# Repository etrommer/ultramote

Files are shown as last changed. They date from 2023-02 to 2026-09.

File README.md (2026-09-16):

# Overview
For a general overview as well as automatically updated documentation, please refer to the [Ultramote website](https://etrommer.github.io/ultramote/)

## Firmware debugging

The firmware debug configuration uses a Black Magic Probe directly as a GDB remote target. It does not require an OpenOCD or pyOCD server. Install `arm-none-eabi-gdb`, build the firmware, and start a direct session with:

```bash
cd firmware
make
arm-none-eabi-gdb build/firmware.elf -x blackmagic.gdb
```

The two Cortex-Debug profiles provide either a flash-and-launch session or an attach-only session.

## Firmware development container

The repository includes a VS Code Dev Container with the pinned STM32CubeMX 6.16.0
Linux package, the STM32CubeWL 1.3.0 firmware package, the GNU Arm Embedded toolchain,
GDB, OpenOCD, and ST-Link tools. Open the repository in VS Code and run **Dev
Containers: Reopen in Container**. The container opens `firmware` as the VS Code
workspace; the repository root is available at `..`.

Build the firmware inside the container:

```bash
make
```

Regenerate CubeMX-managed files from the IOC file without opening a GUI:

```bash
cubemx-generate firmware.ioc
make
```

The image verifies both downloaded archives with SHA-256 checksums. The ST-Link or
Black Magic Probe device must be passed through to the container separately when
debugging; the image does not assume a host device path.

The `pyocd` server type is an alternative only when the connected probe exposes a CMSIS-DAP interface. It is not the transport used by a Black Magic Probe's native GDB interface.

# Firmware
## Remove Lora-E5 readout protection
The Seeedstudio Lora-E5 comes with a preloaded firmware and readout protection enabled. This needs to be disabled before other firmware can be flashed. Run:
```bash
openocd -f interface/stlink.cfg -f target/stm32wlx.cfg
```
then connect to the OpenOCD session from another terminal, using: `nc localhost 4444`. In the telnet session, run:
```
init
reset halt
stm32wlx unlock 0
reset halt
exit
```

# Hardware
## Documentation
Schematics, BoM, Gerber files etc. are generated with the [KiCad command line
interface](https://docs.kicad.org/master/en/cli/cli.html). Change to the `pcb`
directory and run:

```bash
cd pcb
make
```

This generates all documentation in the local subfolder `generated`. `make
docs`, `make fab`, `make step`, `make render` and `make ibom` build single
groups, and `make OUT=<dir>` writes the assets somewhere else. `make` needs
KiCad 10 (`kicad-cli`) and `bsdtar`.

CI runs the same build and publishes the result together with the website
(`.github/workflows/website.yml`). The assets are build output: they are not
committed to the repository, so a local site preview needs

```bash
make -C pcb OUT=website/static/pcb_assets
```

Building the website itself needs Zola 0.22 (`zola --root website build`); 0.23
and later cannot build it, as they replaced the template engine with one that no
longer supports the macros used by the site templates and the `juice` theme.

The interactive BoM needs the
[InteractiveHtmlBom](https://github.com/openscopeproject/InteractiveHtmlBom)
CLI, which must see KiCad's Python bindings. `make` uses one from `PATH` if there
is one, otherwise the copy that ships with the plugin installed through KiCad's
Plugin and Content Manager, so a plugin installation needs no extra setup. Point
`IBOM=` at a CLI from elsewhere (CI installs one from PyPI):

```bash
python3 -m venv --system-site-packages ~/.local/venv/ibom
~/.local/venv/ibom/bin/pip install interactivehtmlbom
make IBOM=~/.local/venv/ibom/bin/generate_interactive_bom
```

If you think that an important piece of documentation is missing, please open an issue.

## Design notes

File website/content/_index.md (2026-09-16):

+++
title = "List of blog posts"
sort_by = "weight"
+++
Ultramote is a long-distance remote trigger system. It is built for photography first, but easily supports all kinds of equipment. Ultramote uses LoRa long-distance radio communication to achieve distances of hunreds of meters, even in urban environments - well above the range of commercially-available 2.4GHz triggering systems. Ultramote lets you put a camera in places where you _really_ don't want to be and allows you to capture shots from a safe distance.

# Hardware
## Interface
Ultramote has two 2.5mm jacks for input and output. Each input/output has two independent channels (tip and sleeve). Output connectors are optically isolated from the Ultramote's electronics, inputs are equipped with high-voltage protection circuitry. Any regular remote shutter or time lapse controller can be connected and is relayed to all Ultramotes listening on the same channel. For camera output, an adapter cable from a 2.5mm jack to the camera's remote port is required.

Ultramote can be connected to a PC via USB-C and controlled via a Serial Terminal.

Firmware updates can also be carried out over USB-C.

## Battery
A 400mAh LiPo battery allows for an idle time of several hours. The battery is charged over USB-C.

## Enclosure
_work in progress_  
The Ultramote's enclosure is 3D-printed in two parts and comes with hotshoe and GoPro-style attachement points as well as a 1/4" thread.

## Extendable
Ultramote is ready to connect to Sparkfun's [QWIIC](https://www.sparkfun.com/qwiic) sensors. This makes it a versatile platform that can support all sorts of sophisticated applications. Want to trigger a remote device depending on temperature, incident light, air pressure, sound, an ultrasonic distance measurement, etc? Integrate your QWIIC sensor into the firmware, flash it using USB and you are good to go!

## Documentation
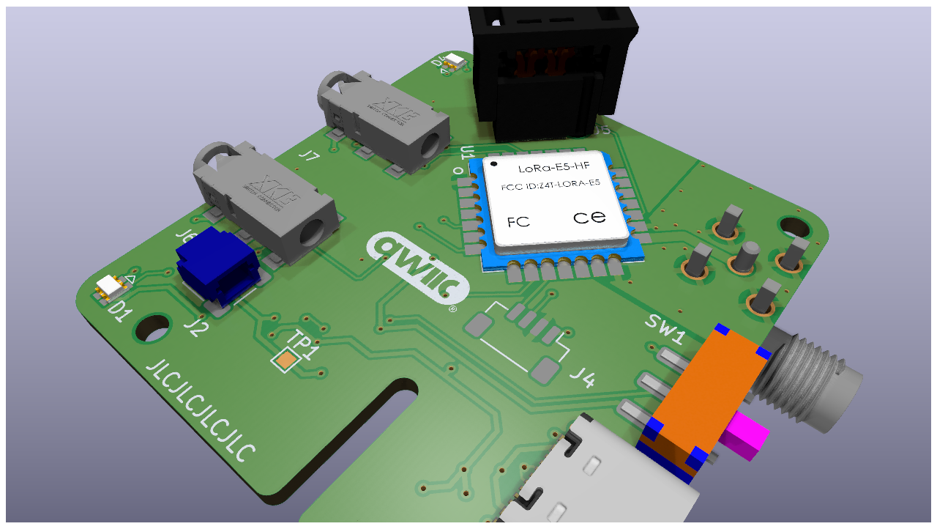
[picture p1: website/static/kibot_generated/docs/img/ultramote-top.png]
Rendering Top

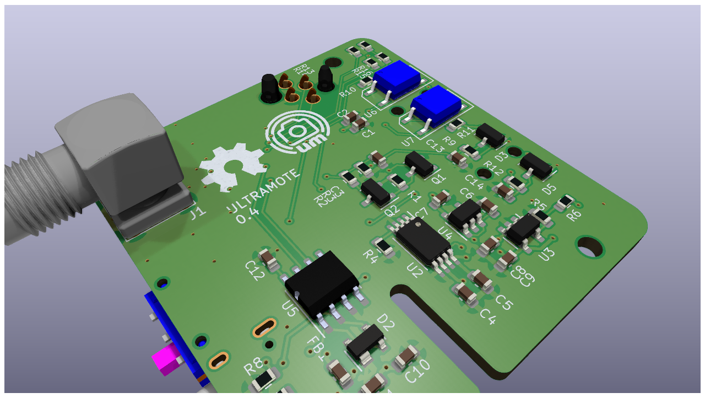
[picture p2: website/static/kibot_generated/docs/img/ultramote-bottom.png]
Rendering Bottom


Documentation is built from the KiCad sources by the `pcb/Makefile` and automatically updated from the repository's main branch
- [Schematic (PDF)](pcb_assets/docs/ultramote-schematic.pdf)
- [Board Layout (PDF)](pcb_assets/docs/ultramote-pcb-layers.pdf)
- [BoM (CSV)](pcb_assets/docs/bom/bom_ultramote.csv)
- [Interactive BoM](pcb_assets/docs/bom/ultramote-ibom.html) (generated using the [KiCAD IBoM Plugin](https://github.com/openscopeproject/InteractiveHtmlBom))
- [CAD File (STEP)](pcb_assets/ultramote.step)

# Firmware
The firmware currently supports these features:
- Pass on trigger events to other devices listening on the same channel
- Report battery voltage
- Command-line interface over USB/Serial. Over the interface, users can:
    - Put the device in bootloader mode to flash firmware over USB. This allows users to easily update their device or develop their own firmware.
    - Reprogram the device to a different channel. Useful when triggering more than one camera.
    - Select LED modes, set the state of the output, inspect device state, etc.

There is a long list of potential features that _might_ be added at a later point in time.

# License
Ultramote Hardware and Software are licensed under the [GNU General Public License v3.0](https://github.com/etrommer/ultramote/tree/main/LICENSE)

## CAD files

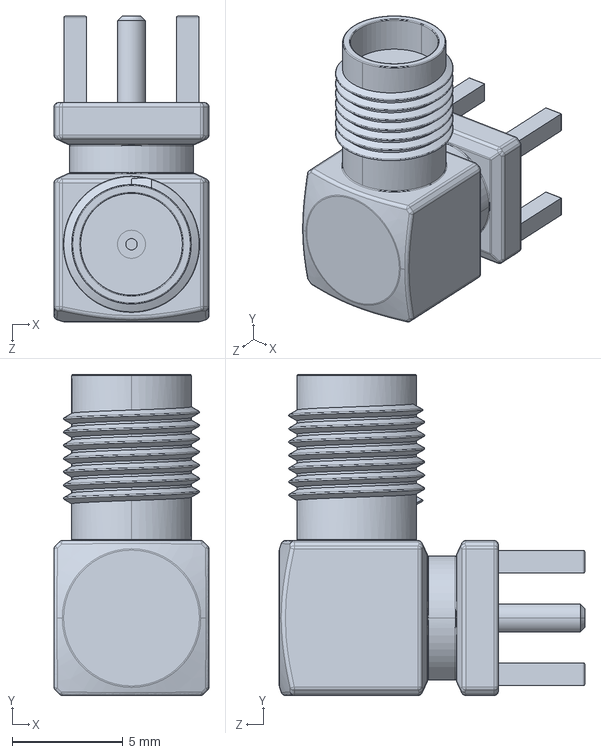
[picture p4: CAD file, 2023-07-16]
pcb/cad_models/SMA ANGLED.STEP
7.00 x 14.5 x 13.8 mm

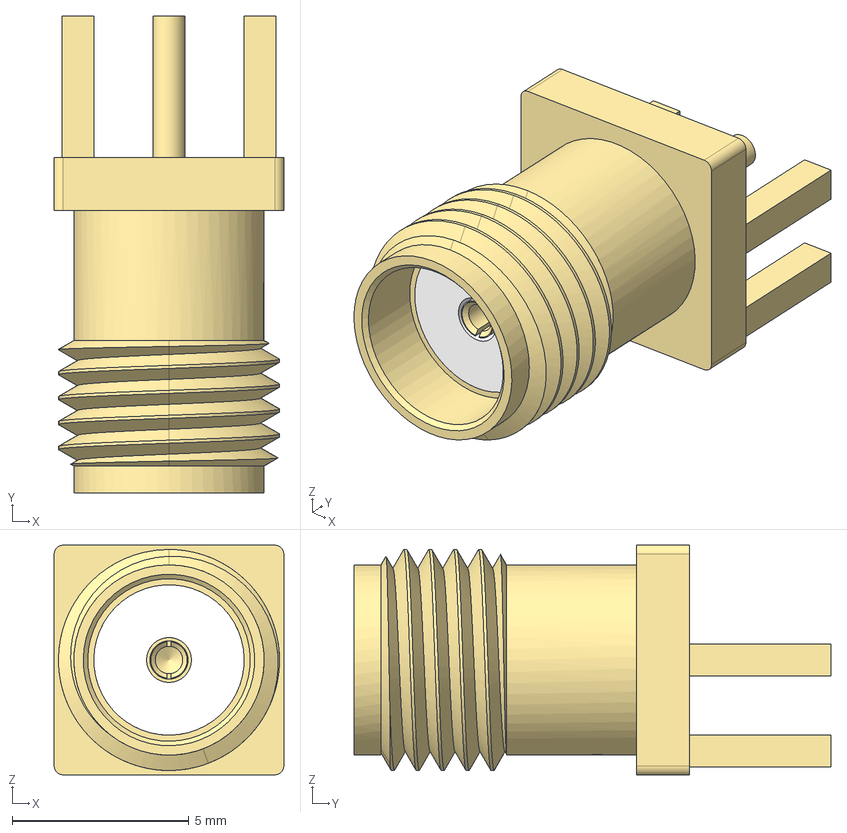
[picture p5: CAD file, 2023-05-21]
pcb/cad_models/SMA_female_edge_6.5x6.5.step
6.50 x 13.5 x 6.50 mm
Dielectric
Pin

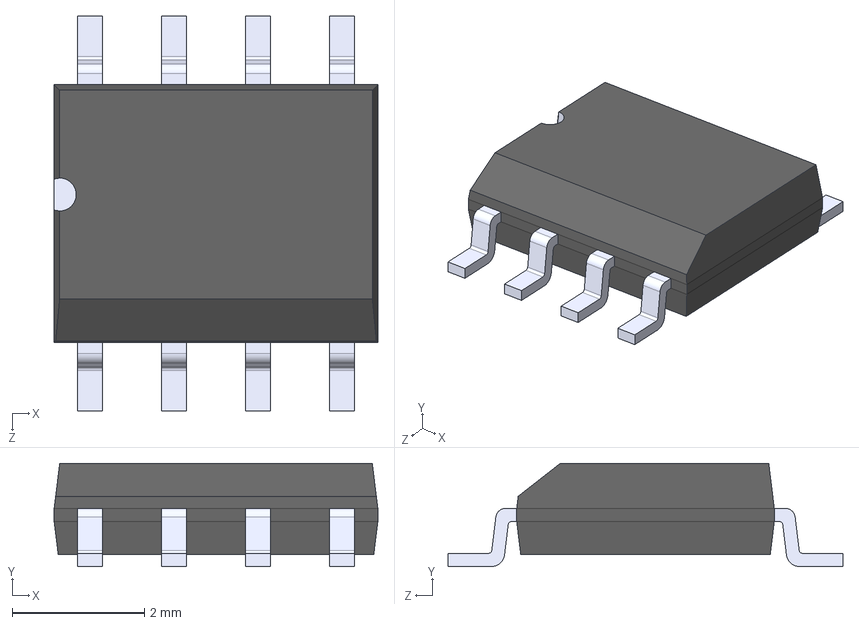
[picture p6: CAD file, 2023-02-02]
pcb/cad_models/sop8.STEP
4.90 x 1.56 x 5.98 mm
User Library-sop8_model_pin5to8_sop8 x 8
User Library-sop8_model_sop8_body

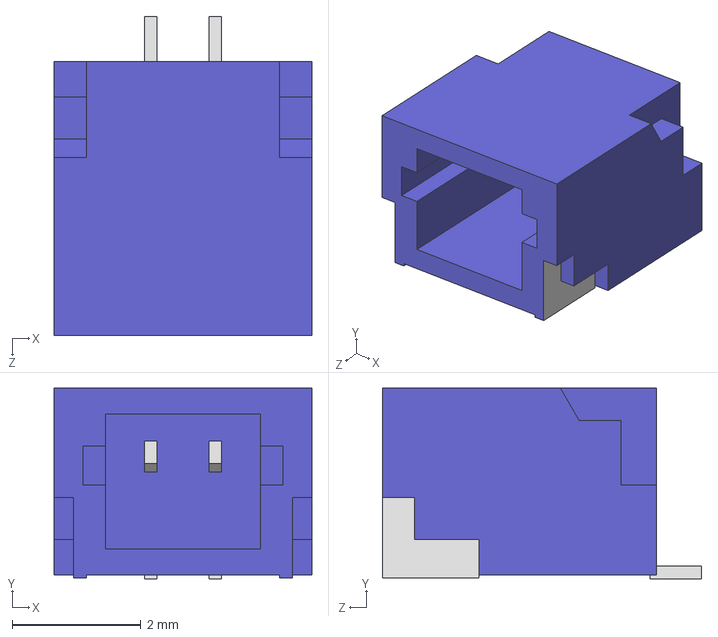
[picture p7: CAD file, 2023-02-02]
pcb/cad_models/SM02B-SRSS-TB.STEP
4.00 x 2.96 x 4.95 mm

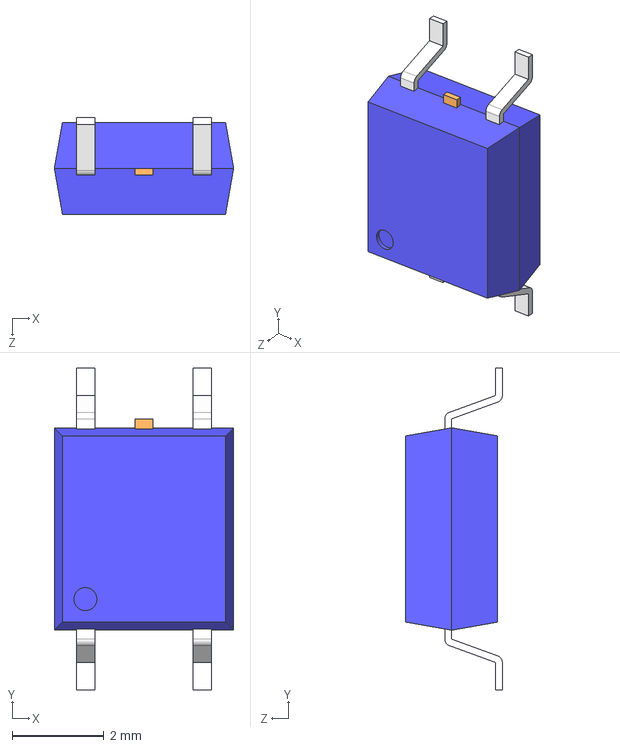
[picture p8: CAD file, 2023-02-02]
pcb/cad_models/sop4.STEP
3.90 x 7.00 x 2.10 mm

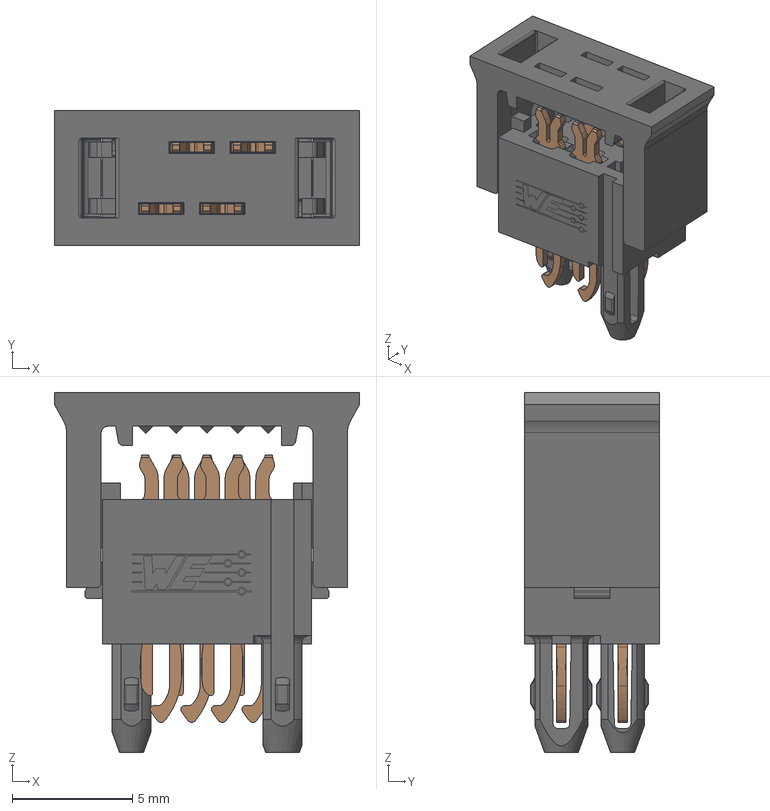
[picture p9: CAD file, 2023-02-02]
pcb/cad_models/redfit_idc_6.stp
12.7 x 5.60 x 15.0 mm
CT422_00.4.1.1_0 x 4
BS698_4_00.4_0000_0
BS697_4_00.6_0000_0

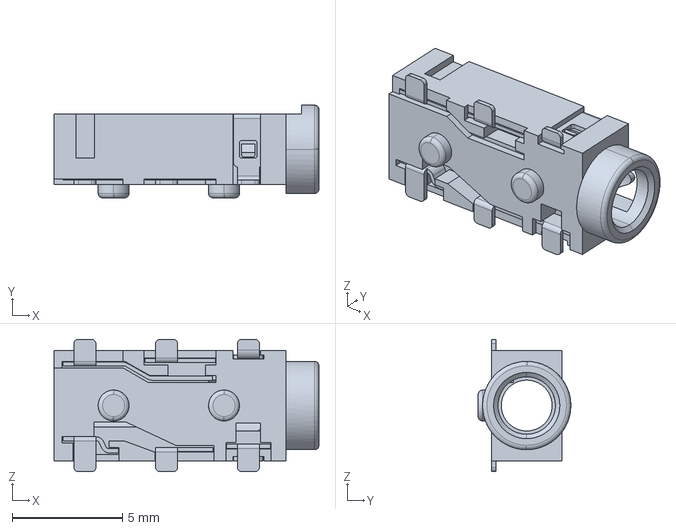
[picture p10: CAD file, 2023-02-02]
pcb/cad_models/pj-242d-smt.stp
12.0 x 4.20 x 6.00 mm

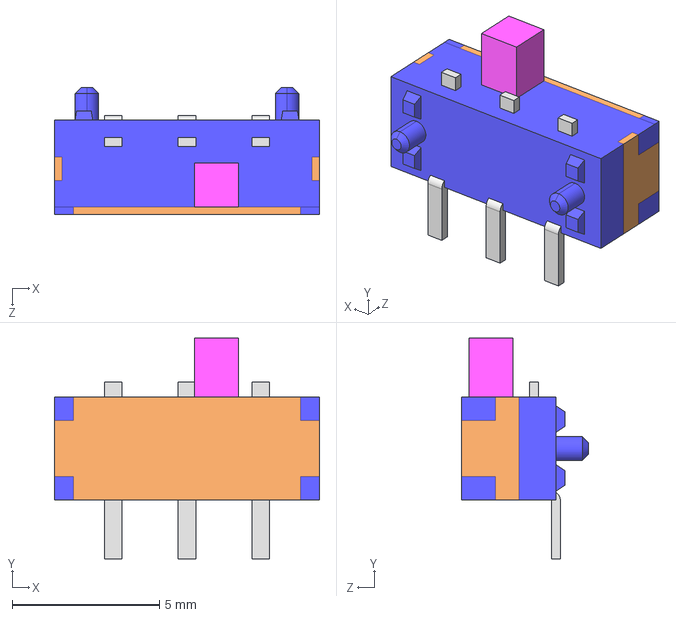
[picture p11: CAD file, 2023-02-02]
pcb/cad_models/SSSS211603.STEP
9.00 x 7.50 x 4.30 mm

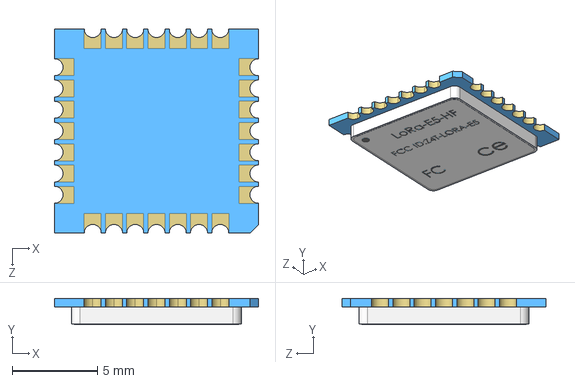
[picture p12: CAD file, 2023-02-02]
pcb/cad_models/lorae5.STEP
12.0 x 1.53 x 12.0 mm

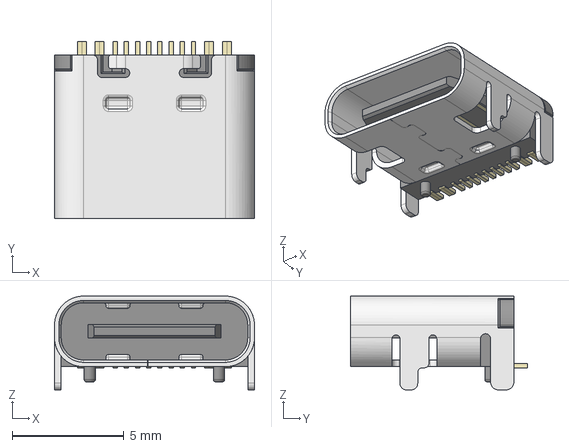
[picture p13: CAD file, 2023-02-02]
pcb/cad_models/USB-C.step
8.95 x 7.90 x 4.20 mm

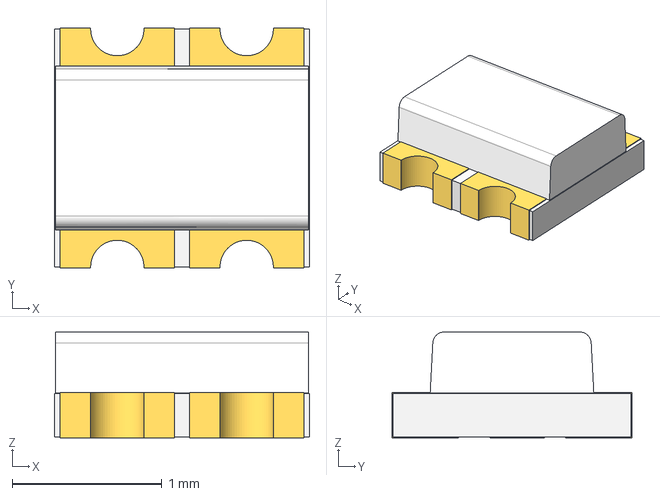
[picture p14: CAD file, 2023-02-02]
pcb/cad_models/led_0606.stp
1.70 x 1.60 x 0.707 mm

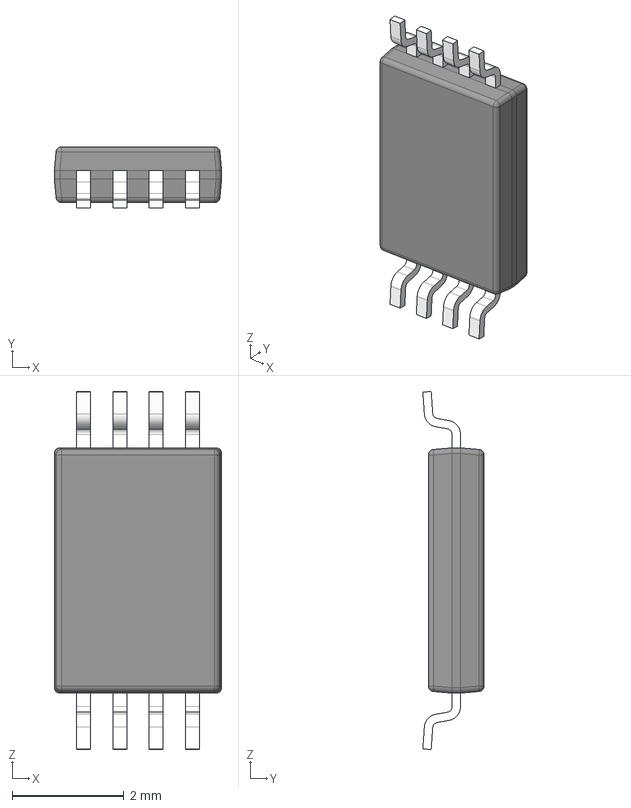
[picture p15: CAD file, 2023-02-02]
pcb/cad_models/tssop8.stp
3.00 x 1.10 x 6.42 mm
BODY-SO
LEAD-SO x 8
PIN1-ID

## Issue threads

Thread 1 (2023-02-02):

Redfit Connector registration pin does not fit

etrommer, 2023-02-02:
One of the registration pins of the Debug connector is larger than the other, but both NPTHs are the same size, so one is a very tight fit.

Fix footprint according to datasheet: https://www.we-online.com/components/products/datasheet/490107670412.pdf

Closed 2023-02-02.

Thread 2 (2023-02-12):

Charge LED is faintly lit when USB is not connected

etrommer, 2023-02-12:
The Lipo charge LED is faintly lit when VBUS = 0V, likely due to backpowering from the MCP73831.

Solution: Power LED from VBUS instead of 3V3. Check if 220 Ohm is still sufficient, as VBUS is 5V.

Closed 2023-06-19.

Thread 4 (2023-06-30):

Assign OUTPUT_TIP to another Pin

etrommer, 2023-06-30:
`OUTPUT_TIP` is currently assigned to `PB0` which interferes with the STM32 clocks.

Pin should be left floating and `OUTPUT_TIP` assigned to another GPIO.

Closed 2023-07-16.

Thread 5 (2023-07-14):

Add I2C/QWIIC capability

etrommer, 2023-07-14:
Adding the capability to easily add I2C sensors etc. might be a good idea to increase versatility and reuse.
`PB6` and `PB9` of `I2C1` are not currently used and could support a [QWIIC connector](https://www.sparkfun.com/qwiic) footprint.

Closed 2023-07-16.

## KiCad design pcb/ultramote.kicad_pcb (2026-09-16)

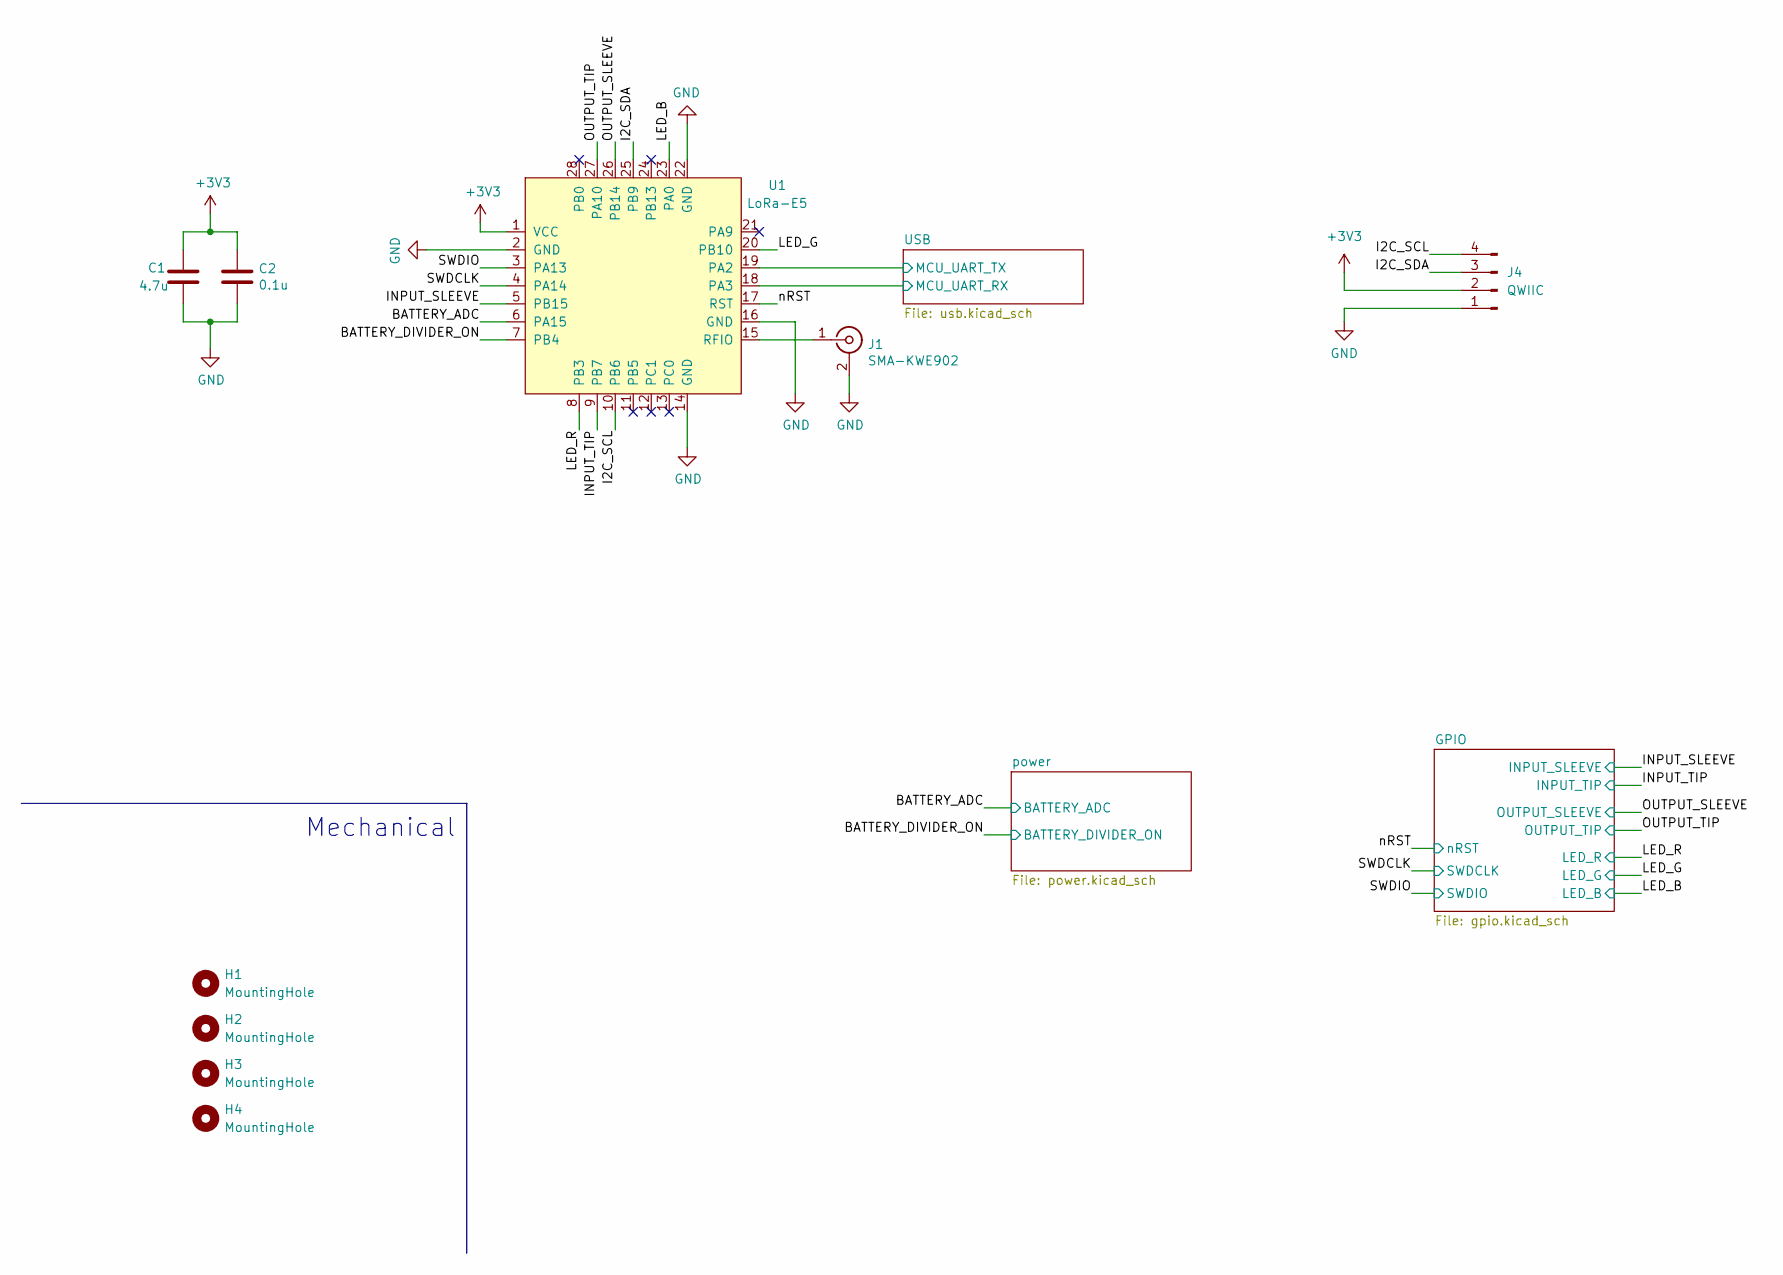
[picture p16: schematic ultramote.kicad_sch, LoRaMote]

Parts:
C1: 4.7u; C_0603_1608Metric; Manufacturer Part Number CL10A475MA8NQNC; LCSC Part Number C913907
C2: 0.1u; C_0603_1608Metric; Manufacturer Part Number CL10B104KB8SNNC; LCSC Part Number C570192
H1, H2, H3, H4: MountingHole; MountingHole_2.2mm_M2
J1: SMA-KWE902; Manufacturer Part Number SMA-KE-P903; LCSC Part Number C914554
J4: QWIIC; JST_SH_BM04B-SRSS-TB_1x04-1MP_P1.00mm_Vertical
U1: LoRa-E5

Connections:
+3V3: C1.1, C2.1, J4.2, U1.1 (VCC); also elsewhere on the board
/BATTERY_ADC: U1.6 (PA15); also elsewhere on the board
/BATTERY_DIVIDER_ON: U1.7 (PB4); also elsewhere on the board
/I2C_SCL: J4.4, U1.10 (PB6)
/I2C_SDA: J4.3, U1.25 (PB9)
/INPUT_SLEEVE: U1.5 (PB15); also elsewhere on the board
/INPUT_TIP: U1.9 (PB7); also elsewhere on the board
/LED_B: U1.23 (PA0); also elsewhere on the board
/LED_G: U1.20 (PB10); also elsewhere on the board
/LED_R: U1.8 (PB3); also elsewhere on the board
/OUTPUT_SLEEVE: U1.26 (PB14); also elsewhere on the board
/OUTPUT_TIP: U1.27 (PA10); also elsewhere on the board
/SWDCLK: U1.4 (PA14); also elsewhere on the board
/SWDIO: U1.3 (PA13); also elsewhere on the board
/USB/MCU_UART_RX: U1.18 (PA3); also elsewhere on the board
/USB/MCU_UART_TX: U1.19 (PA2); also elsewhere on the board
/nRST: U1.17 (RST); also elsewhere on the board
GND: C1.2, C2.2, J1.2 (Ext), J4.1, U1.2 (GND), U1.14 (GND), U1.16 (GND), U1.22 (GND); also elsewhere on the board
unnamed: J1.1 (In), U1.15 (RFIO)

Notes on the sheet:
Mechanical

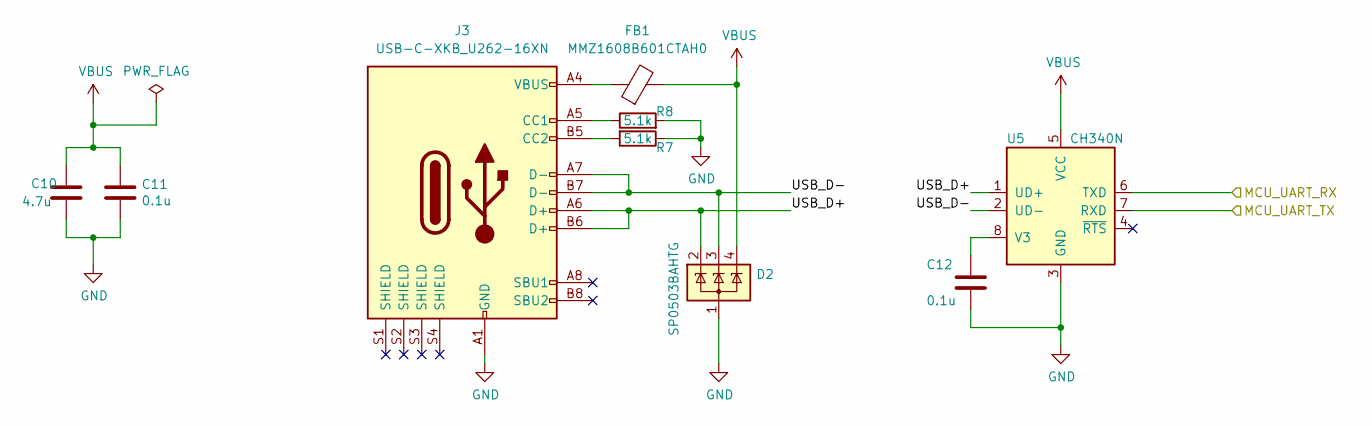
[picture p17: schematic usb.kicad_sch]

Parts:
C10: 4.7u; C_0603_1608Metric; Manufacturer Part Number CL10A475MA8NQNC; LCSC Part Number C913907
C11, C12: 0.1u; C_0603_1608Metric; Manufacturer Part Number CL10B104KB8SNNC; LCSC Part Number C570192
D2: SP0503BAHTG; SOT-143; Manufacturer Part Number TPSP0503BAHTG; LCSC Part Number C2682275
FB1: MMZ1608B601CTAH0; C_0603_1608Metric; Manufacturer Part Number MMZ1608B601CTAH0; LCSC Part Number C97120
J3: USB-C-XKB_U262-16XN; USB_C_Receptacle_XKB_U262-16XN-4BVC11; Manufacturer Part Number 918-418K2023S40001; LCSC Part Number C167321
R7, R8: 5.1k; R_0603_1608Metric; Manufacturer Part Number 0603WAF5101T5E; LCSC Part Number C23186
U5: CH340N; SOP-8_3.9x4.9mm_P1.27mm; Manufacturer Part Number CH340N; LCSC Part Number C2977777

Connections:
/USB/MCU_UART_RX: U5.6 (TXD); also elsewhere on the board
/USB/MCU_UART_TX: U5.7 (RXD); also elsewhere on the board
/USB/USB_D+: D2.2 (K), J3.A6 (D+), J3.B6 (D+), U5.1 (UD+)
/USB/USB_D-: D2.3 (K), J3.A7 (D-), J3.B7 (D-), U5.2 (UD-)
GND: C10.2, C11.2, C12.2, D2.1 (A), J3.A1 (GND), J3.A12 (GND), J3.B1 (GND), J3.B12 (GND), R7.2, R8.1, U5.3 (GND); also elsewhere on the board
unnamed: FB1.1, J3.A4 (VBUS), J3.A9 (VBUS), J3.B4 (VBUS), J3.B9 (VBUS)
unnamed: J3.A5 (CC1), R7.1
unnamed: J3.B5 (CC2), R8.2
unnamed: C12.1, U5.8 (V3)
VBUS: C10.1, C11.1, D2.4 (K), FB1.2, U5.5 (VCC); also elsewhere on the board

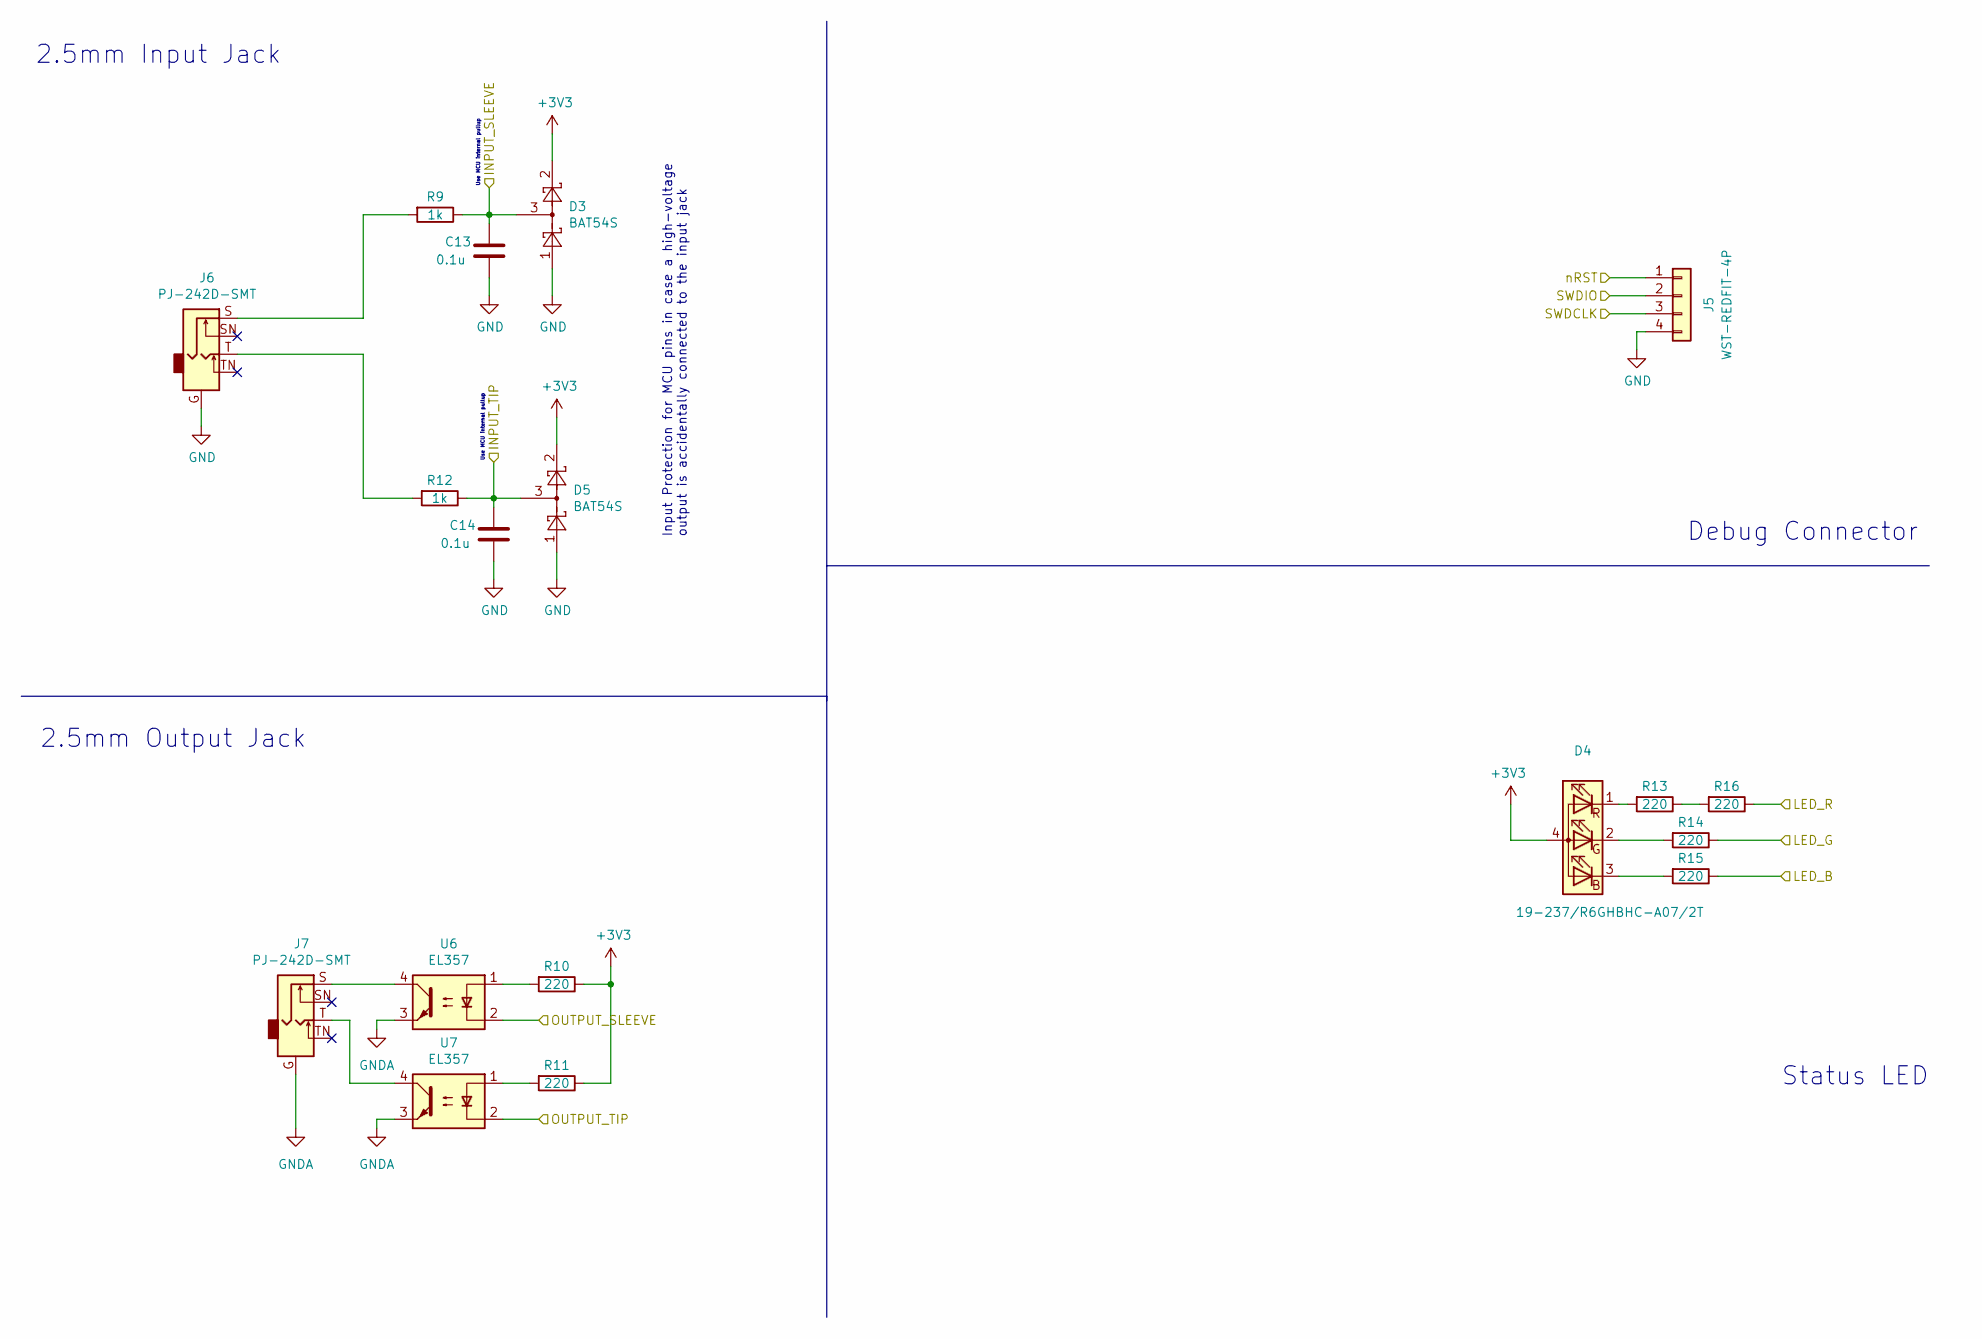
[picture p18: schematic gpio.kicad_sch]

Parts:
C13, C14: 0.1u; C_0603_1608Metric; Manufacturer Part Number CL10B104KB8SNNC; LCSC Part Number C570192
D3, D5: BAT54S; SOT-23; Manufacturer Part Number BAT54S; LCSC Part Number C408389
D4: 19-237/R6GHBHC-A07/2T; 19-237-R6GHBHC-A01-2T; Manufacturer Part Number 19-237/R6GHBHC-A07/2T; LCSC Part Number C264511
J5: WST-REDFIT-4P; WR_WST-REDFIT-4P_DEBUG
J6, J7: PJ-242D-SMT; Manufacturer Part Number PJ-242D-SMT; LCSC Part Number C381133
R9, R12: 1k; R_0603_1608Metric; Manufacturer Part Number 0603WAF1001T5E; LCSC Part Number C21190
R10, R11, R13, R14, R15, R16: 220; R_0603_1608Metric; Manufacturer Part Number 0603WAF2200T5E; LCSC Part Number C22962
U6, U7: EL357; EL357N-G; Manufacturer Part Number EL357N(B)(TA)-G; LCSC Part Number C6649

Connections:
+3V3: D3.2, D4.4 (A), D5.2, R10.1, R11.1; also elsewhere on the board
/INPUT_SLEEVE: C13.1, D3.3, R9.1; also elsewhere on the board
/INPUT_TIP: C14.1, D5.3, R12.1; also elsewhere on the board
/LED_B: R15.1; also elsewhere on the board
/LED_G: R14.1; also elsewhere on the board
/LED_R: R16.1; also elsewhere on the board
/OUTPUT_SLEEVE: U6.2; also elsewhere on the board
/OUTPUT_TIP: U7.2; also elsewhere on the board
/SWDCLK: J5.3; also elsewhere on the board
/SWDIO: J5.2; also elsewhere on the board
/nRST: J5.1; also elsewhere on the board
GND: C13.2, C14.2, D3.1, D5.1, J5.4, J6.G; also elsewhere on the board
GNDA: J7.G, U6.3, U7.3
unnamed: D4.3 (BK), R15.2
unnamed: D4.2 (GK), R14.2
unnamed: D4.1 (RK), R13.2
unnamed: J6.S, R9.2
unnamed: J6.T, R12.2
unnamed: J7.S, U6.4
unnamed: J7.T, U7.4
unnamed: R10.2, U6.1
unnamed: R11.2, U7.1
unnamed: R13.1, R16.2

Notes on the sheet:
Status LED
Input Protection for MCU pins in case a high-voltage output is accidentally connected to the input jack
2.5mm Output Jack
2.5mm Input Jack
Use MCU internal pullup
Debug Connector

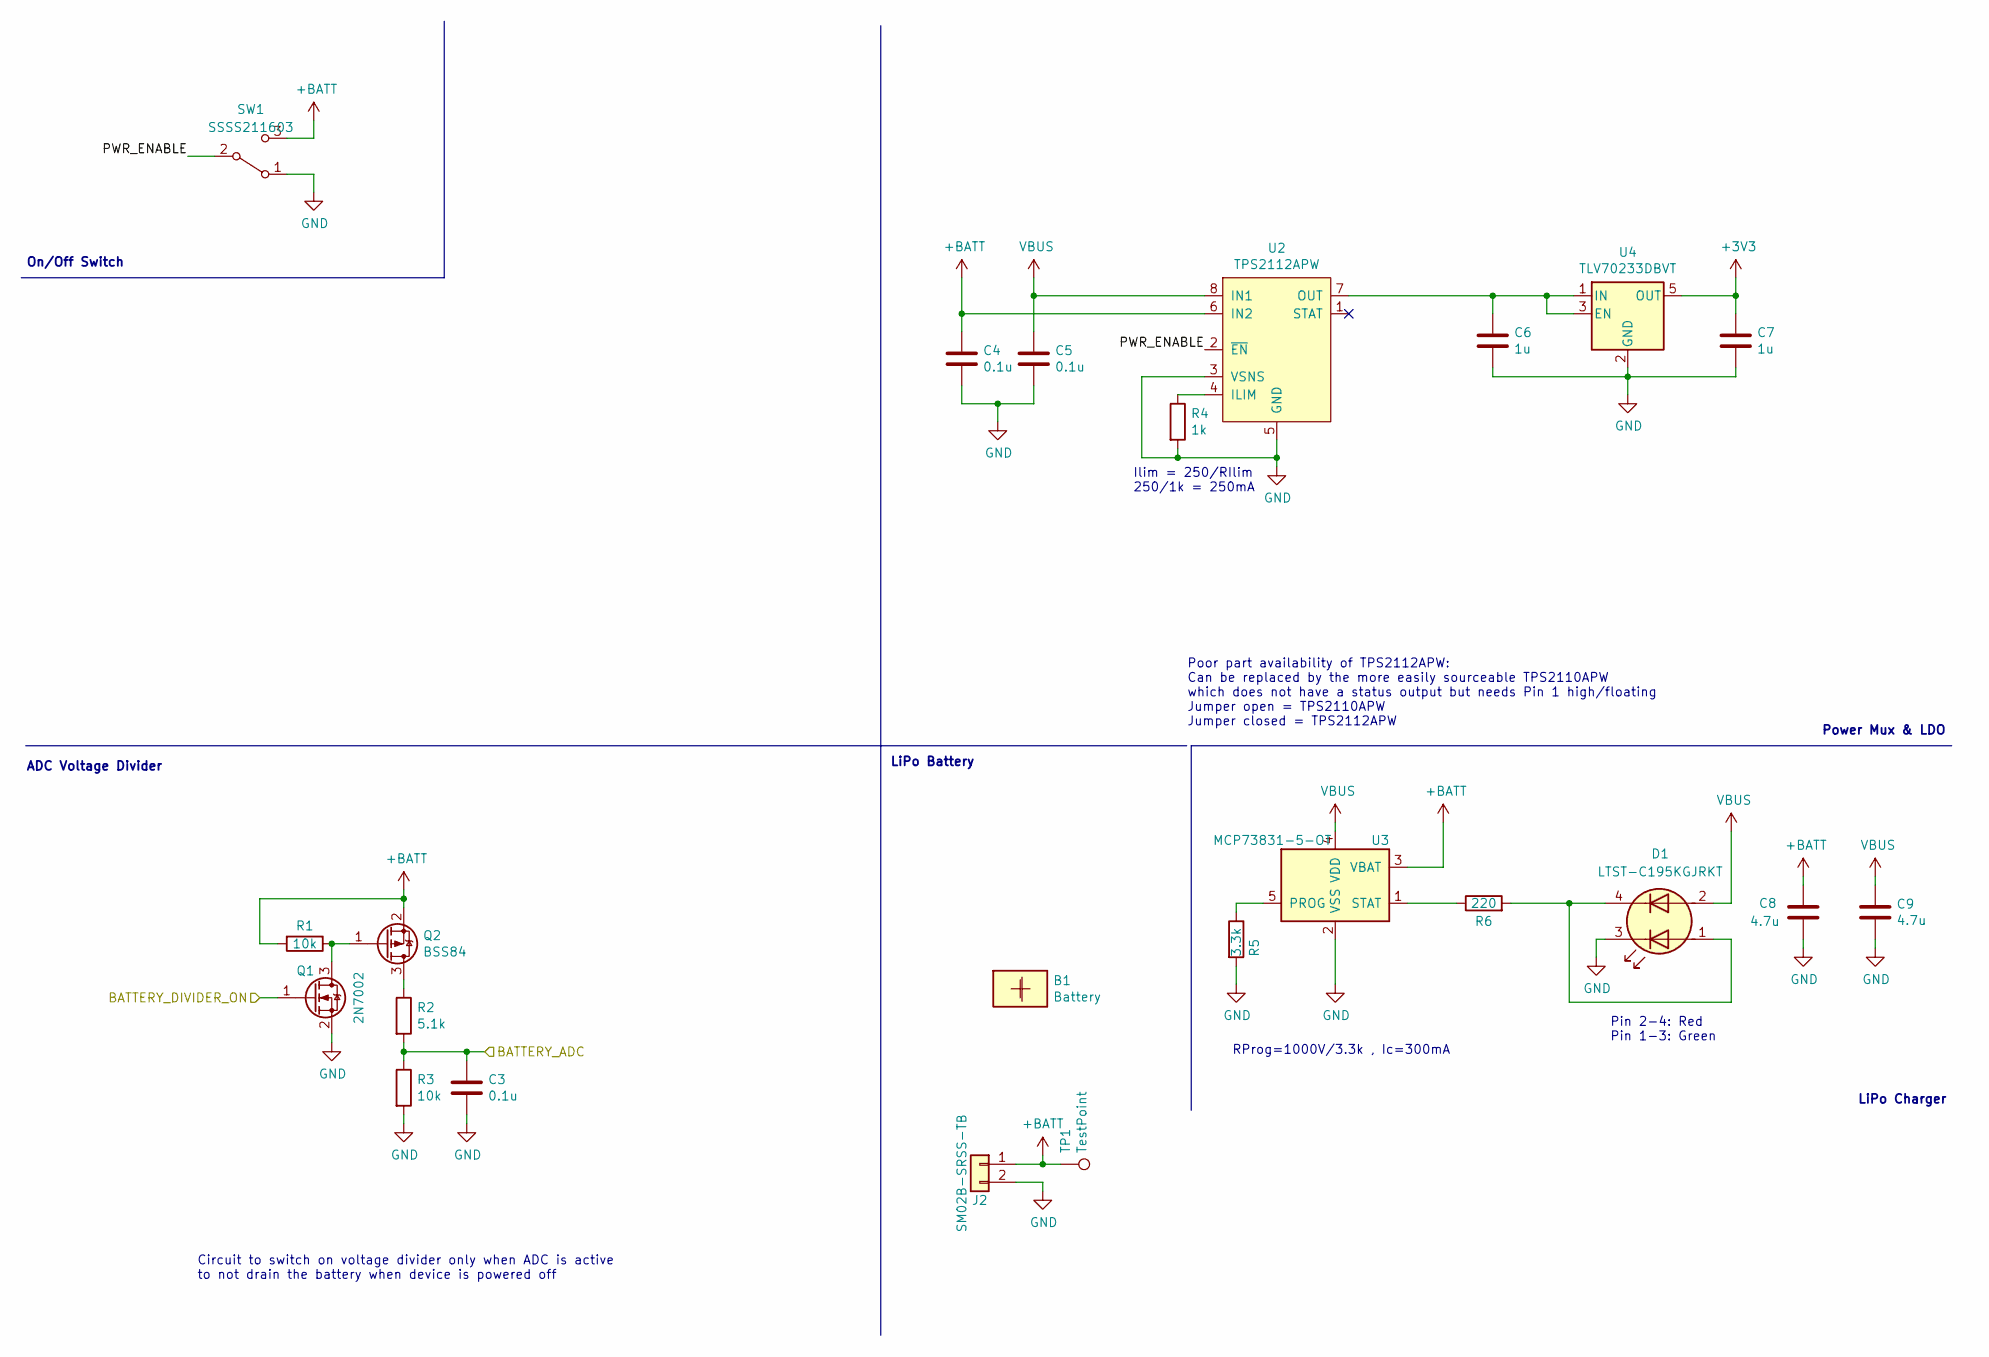
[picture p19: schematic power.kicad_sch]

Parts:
B1: Battery; lipo403030_300mah
C3, C4, C5: 0.1u; C_0603_1608Metric; Manufacturer Part Number CL10B104KB8SNNC; LCSC Part Number C570192
C6, C7: 1u; C_0603_1608Metric; Manufacturer Part Number CL10B105KA8NNNC; LCSC Part Number C29936
C8, C9: 4.7u; C_0603_1608Metric; Manufacturer Part Number CL10A475MA8NQNC; LCSC Part Number C913907
D1: LTST-C195KGJRKT; Manufacturer Part Number LTST-C195KGJRKT; LCSC Part Number C125104
J2: SM02B-SRSS-TB; JST_SH_SM02B-SRSS-TB_1x02-1MP_P1.00mm_Horizontal; Manufacturer Part Number S2B-PH-SM4-TB(LF)(SN); LCSC Part Number C160402
Q1: 2N7002; SOT-23; Manufacturer Part Number 2N7002; LCSC Part Number C916396
Q2: BSS84; SOT-23; Manufacturer Part Number BSS84A-TP; LCSC Part Number C668883
R1, R3: 10k; R_0603_1608Metric; Manufacturer Part Number 0603WAF1002T5E; LCSC Part Number C25804
R2: 5.1k; R_0603_1608Metric; Manufacturer Part Number 0603WAF5101T5E; LCSC Part Number C23186
R4: 1k; R_0603_1608Metric; Manufacturer Part Number 0603WAF1001T5E; LCSC Part Number C21190
R5: 3.3k; R_0603_1608Metric; Manufacturer Part Number 0603WAF3301T5E; LCSC Part Number C22978
R6: 220; R_0603_1608Metric; Manufacturer Part Number 0603WAF2200T5E; LCSC Part Number C22962
SW1: SSSS211603; Manufacturer Part Number SSSS211603; LCSC Part Number C125040
TP1: TestPoint; TestPoint_Pad_1.0x1.0mm
U2: TPS2112APW; TSSOP-8_4.4x3mm_P0.65mm; Manufacturer Part Number TPS2112APW; LCSC Part Number C1524008
U3: MCP73831-5-OT; SOT-23-5; Manufacturer Part Number MCP73831T-2ACI/OT; LCSC Part Number C424093
U4: TLV70233DBVT; SOT-23-5; Manufacturer Part Number TLV70233DBVT; LCSC Part Number C110287

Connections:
+3V3: C7.1, U4.5 (OUT); also elsewhere on the board
+BATT: C4.1, C8.1, J2.1, Q2.2 (S), R1.2, SW1.3 (C), TP1.1, U2.6 (IN2), U3.3 (VBAT)
/BATTERY_ADC: C3.1, R2.2, R3.1; also elsewhere on the board
/BATTERY_DIVIDER_ON: Q1.1 (G); also elsewhere on the board
/power/PWR_ENABLE: SW1.2 (B), U2.2 (~EN)
GND: C3.2, C4.2, C5.2, C6.2, C7.2, C8.2, C9.2, D1.3 (K1), J2.2, Q1.2 (S), R3.2, R4.2, R5.2, SW1.1 (A), U2.3 (VSNS), U2.5 (GND), U3.2 (VSS), U4.2 (GND); also elsewhere on the board
unnamed: D1.1 (A1), D1.4 (K2), R6.2
unnamed: Q1.3 (D), Q2.1 (G), R1.1
unnamed: Q2.3 (D), R2.1
unnamed: R4.1, U2.4 (ILIM)
unnamed: C6.1, U2.7 (OUT), U4.1 (IN), U4.3 (EN)
unnamed: R5.1, U3.5 (PROG)
unnamed: R6.1, U3.1 (STAT)
VBUS: C5.1, C9.1, D1.2 (A2), U2.8 (IN1), U3.4 (VDD); also elsewhere on the board

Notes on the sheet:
Poor part availability of TPS2112APW: Can be replaced by the more easily sourceable TPS2110APW which does not have a status output but needs Pin 1 high/floating Jumper open = TPS2110APW Jumper closed = TPS2112APW
LiPo Charger
ADC Voltage Divider
Pin 2-4: Red Pin 1-3: Green
Circuit to switch on voltage divider only when ADC is active to not drain the battery when device is powered off
Ilim = 250/RIlim 250/1k = 250mA
RProg=1000V/3.3k , Ic=300mA
Power Mux & LDO
On/Off Switch
LiPo Battery

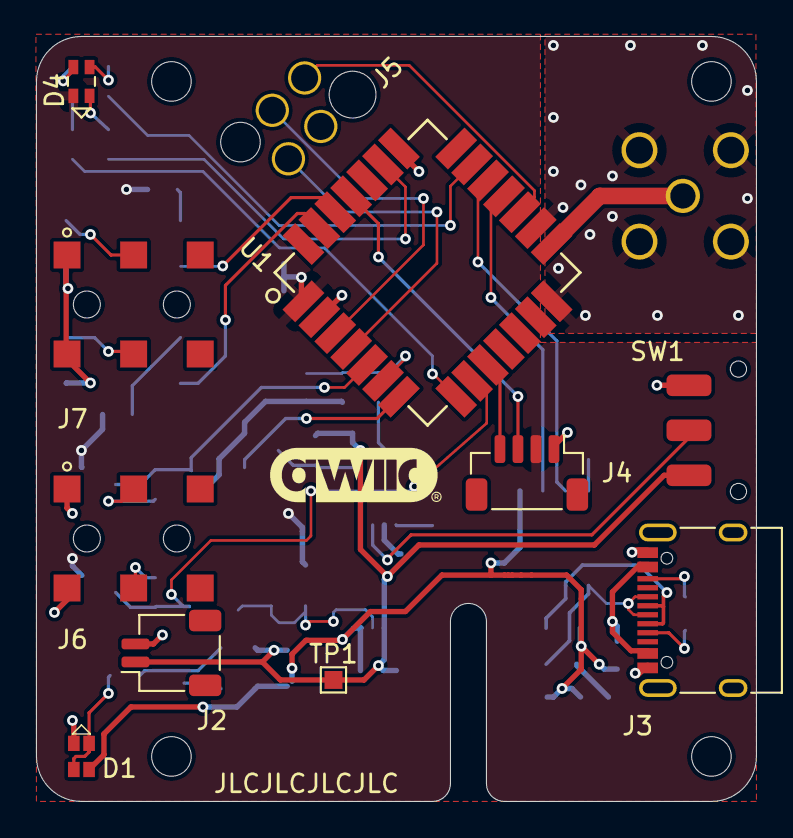
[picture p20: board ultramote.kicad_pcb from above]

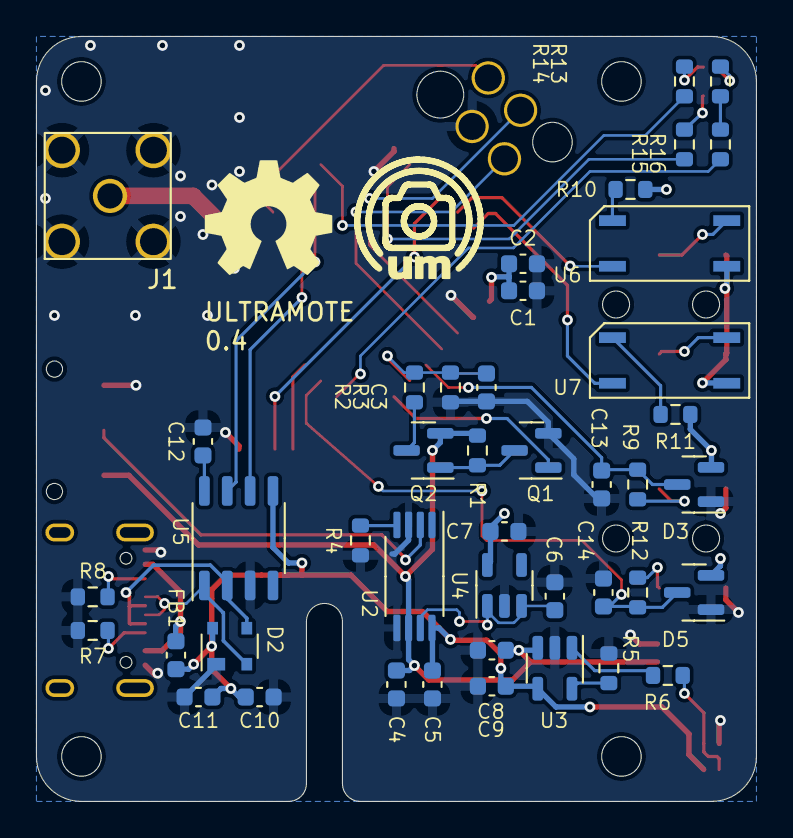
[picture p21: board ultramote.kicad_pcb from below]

Board: 2 copper layers, 40.0 x 42.5 mm, 59 parts (43 on the bottom side), 46 nets.

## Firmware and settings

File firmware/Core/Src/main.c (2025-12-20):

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
/* Includes ------------------------------------------------------------------*/
#include "main.h"
#include "adc.h"
#include "dma.h"
#include "i2c.h"
#include "tim.h"
#include "usart.h"
#include "gpio.h"

/* USER CODE BEGIN Includes */
#include "app.h"
#include "bootloader.h"
/* USER CODE END Includes */


void SystemClock_Config(void);
/**
 * @brief  The application entry point.
 * @retval int
 */
int main(void)
{

  /* USER CODE BEGIN 1 */

  // Pre-init:
  // Check if entering the bootloader was requested
  // before reset
  bootloader_check();

  /* USER CODE END 1 */

  /* MCU Configuration--------------------------------------------------------*/

  /* Reset of all peripherals, Initializes the Flash interface and the Systick. */
  HAL_Init();

  /* Configure the system clock */
  SystemClock_Config();

  /* Initialize all configured peripherals */
  MX_GPIO_Init();
  MX_DMA_Init();
  MX_TIM2_Init();
  MX_ADC_Init();
  MX_USART2_UART_Init();
  MX_TIM17_Init();
  MX_I2C1_Init();
  /* USER CODE BEGIN 2 */

  app_init();

  // volatile flash_backup_t *foo = flash_backup_read();

  // uint32_t len = 0;
  // uint8_t buffer[8];
  // uint32_t last_tick = HAL_GetTick();
  /* USER CODE END 2 */

  /* Infinite loop */
  /* USER CODE BEGIN WHILE */
  while (1)
  {

    app_main_loop();
    /* USER CODE END WHILE */

    /* USER CODE BEGIN 3 */
  }
  /* USER CODE END 3 */
}

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


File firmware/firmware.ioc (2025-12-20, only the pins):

Mcu.UserName=STM32WLE5JCIx
PA0.GPIO_Label=LED_B
PA0.Signal=S_TIM2_CH1
PA10.GPIO_Label=OUTPUT_TIP
PA10.Signal=GPIO_Output
PA13.Signal=DEBUG_JTMS-SWDIO
PA14.Signal=DEBUG_JTCK-SWCLK
PA15.Signal=ADC_IN11
PA2.Signal=USART2_TX
PA3.Signal=USART2_RX
PB0-VDD_TCXO.Signal=VDDTCXO
PB10.GPIO_Label=LED_G
PB10.Signal=S_TIM2_CH3
PB14.GPIO_Label=OUTPUT_SLEEVE
PB14.Signal=GPIO_Output
PB15.GPIO_Label=INPUT_SLEEVE
PB15.Signal=GPIO_Input
PB3.GPIO_Label=LED_R
PB3.Signal=S_TIM2_CH2
PB4.GPIO_Label=BATTERY_DIVIDER_ON
PB4.Signal=GPIO_Output
PB6.Signal=I2C1_SCL
PB7.GPIO_Label=INPUT_TIP
PB7.Signal=GPIO_Input
PB9.Signal=I2C1_SDA
PC14-OSC32_IN.Signal=RCC_OSC32_IN
PC15-OSC32_OUT.Signal=RCC_OSC32_OUT

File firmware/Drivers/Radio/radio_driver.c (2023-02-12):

/*!
 * \file      radio_driver.c
 *
 * \brief     radio driver implementation
 *
 * \copyright Revised BSD License, see section \ref LICENSE.
 *
 * \code
 *                ______                              _
 *               / _____)             _              | |
 *              ( (____  _____ ____ _| |_ _____  ____| |__
 *               \____ \| ___ |    (_   _) ___ |/ ___)  _ \
 *               _____) ) ____| | | || |_| ____( (___| | | |
 *              (______/|_____)_|_|_| \__)_____)\____)_| |_|
 *              (C)2013-2017 Semtech
 *
 * \endcode
 *
 * \author    Miguel Luis ( Semtech )
 *
 * \author    Gregory Cristian ( Semtech )
 */
/**
 ******************************************************************************
 *
 *          Portions COPYRIGHT 2020 STMicroelectronics
 *
 * @file    radio_driver.c
 * @author  MCD Application Team
 * @brief   radio driver implementation
 ******************************************************************************
 */
/* Includes ------------------------------------------------------------------*/
#include "radio_conf.h"
#include "radio_driver.h"
//#include "mw_log_conf.h"

/* External variables ---------------------------------------------------------*/
/*!
 * \brief Sughz handler
 */
extern SUBGHZ_HandleTypeDef hsubghz;

/* Private typedef -----------------------------------------------------------*/
/*!
 * FSK bandwidth definition
 */
typedef struct FskBandwidth_s
{
    uint32_t bandwidth;
    uint8_t RegValue;
} FskBandwidth_t;
/* Private define ------------------------------------------------------------*/
/**
 * @brief drive value used anytime radio is NOT in TX low power mode
 * @note SMPS_DRIVE_SETTING_DEFAULT can be redefined in radio_conf.h
 */
#ifndef SMPS_DRIVE_SETTING_DEFAULT
#define SMPS_DRIVE_SETTING_DEFAULT SMPS_DRV_40
#endif /* SMPS_DRIVE_SETTING_DEFAULT */

/**
 * @brief drive value used anytime radio is in TX low power mode
 *        TX low power mode is the worst case because the PA sinks from SMPS
 *        while in high power mode, current is sunk directly from the battery
 * @note SMPS_DRIVE_SETTING_MAX can be redefined in radio_conf.h
 */
#ifndef SMPS_DRIVE_SETTING_MAX
#define SMPS_DRIVE_SETTING_MAX SMPS_DRV_60
#endif /* SMPS_DRIVE_SETTING_MAX */

/**
 * @brief Provides the frequency of the chip running on the radio and the frequency step
 * @remark These defines are used for computing the frequency divider to set the RF frequency
 * @note XTAL_FREQ can be redefined in radio_conf.h
 */
#ifndef XTAL_FREQ
#define XTAL_FREQ (32000000UL)
#endif /* XTAL_FREQ */

/**
 * @brief in XO mode, set internal capacitor (from 0x00 to 0x2F starting 11.2pF with 0.47pF steps)
 * @note XTAL_DEFAULT_CAP_VALUE can be redefined in radio_conf.h
 */
#ifndef XTAL_DEFAULT_CAP_VALUE
#define XTAL_DEFAULT_CAP_VALUE (0x20UL)
#endif /* XTAL_DEFAULT_CAP_VALUE */

/**
 * @brief voltage of vdd tcxo.
 * @note TCXO_CTRL_VOLTAGE can be redefined in radio_conf.h
 */
#ifndef TCXO_CTRL_VOLTAGE
#define TCXO_CTRL_VOLTAGE TCXO_CTRL_1_7V
#endif /* TCXO_CTRL_VOLTAGE */

/**
 * @brief Radio maximum wakeup time (in ms)
 * @note RF_WAKEUP_TIME can be redefined in radio_conf.h
 */
#ifndef RF_WAKEUP_TIME
#define RF_WAKEUP_TIME (10UL)
#endif /* RF_WAKEUP_TIME */

/**
 * @brief DCDC is present and enabled
 * @remark this define is only used if the DCDC is present on the board
 * @note DCDC_ENABLE can be redefined in radio_conf.h
 */
#ifndef DCDC_ENABLE
#define DCDC_ENABLE (1UL)
#endif /* DCDC_ENABLE */

/* Private macro -------------------------------------------------------------*/

#define SX_FREQ_TO_CHANNEL(channel, freq)                             \
    do                                                                \
    {                                                                 \
        channel = (uint32_t)((((uint64_t)freq) << 25) / (XTAL_FREQ)); \
    } while (0)

/* Private variables ---------------------------------------------------------*/
/*!
 * \brief Holds the internal operating mode of the radio
 */
static RadioOperatingModes_t OperatingMode;

/*!
 * \brief Stores the current packet type set in the radio
 */
static RadioPacketTypes_t PacketType;

/*!
 * \brief Stores the current packet header type set in the radio
 */
static volatile RadioLoRaPacketLengthsMode_t LoRaHeaderType;

/*!
 * \brief Stores the last frequency error measured on LoRa received packet
 */
volatile uint32_t FrequencyError = 0;

/*!
 * \brief Hold the status of the Image calibration
 */
static bool ImageCalibrated = false;

/*!
 * Precomputed FSK bandwidth registers values
 */
static const FskBandwidth_t FskBandwidths[] =
    {
        {4800, 0x1F},
        {5800, 0x17},
        {7300, 0x0F},
        {9700, 0x1E},
        {11700, 0x16},
        {14600, 0x0E},
        {19500, 0x1D},
        {23400, 0x15},
        {29300, 0x0D},
        {39000, 0x1C},
        {46900, 0x14},
        {58600, 0x0C},
        {78200, 0x1B},
        {93800, 0x13},
        {117300, 0x0B},
        {156200, 0x1A},
        {187200, 0x12},
        {234300, 0x0A},
        {312000, 0x19},
        {373600, 0x11},
        {467000, 0x09},
        {500000, 0x00}, // Invalid Bandwidth
};

/* Private function prototypes -----------------------------------------------*/

/*!
 * \brief This set SMPS drive capability wrt. RF mode
 *
 * \param [in]  level       SMPS maximum drive capability level
 */
static void Radio_SMPS_Set(uint8_t level);

/*!
 * \brief IRQ Callback radio function
 */
static DioIrqHandler RadioOnDioIrqCb;

/*!
 * \brief Write command to the radio
 *
 * \param [in]  Command       The Write Command
 * \param [out] pBuffer       A pointer command buffer
 * \param [in]  Size          Size in byte of the command buffer
 */
static void SUBGRF_WriteCommand(SUBGHZ_RadioSetCmd_t Command, uint8_t *pBuffer,
                                uint16_t Size);
/*!
 * \brief Read command to the radio
 *
 * \param [in]  Command       The Read Command
 * \param [out] pBuffer       A pointer command buffer
 * \param [in]  Size          Size in byte of the command buffer
 */
static void SUBGRF_ReadCommand(SUBGHZ_RadioGetCmd_t Command, uint8_t *pBuffer,
                               uint16_t Size);
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

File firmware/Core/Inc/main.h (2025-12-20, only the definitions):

#define RTC_N_PREDIV_S 10
#define RTC_PREDIV_S ((1 << RTC_N_PREDIV_S) - 1)
#define RTC_PREDIV_A ((1 << (15 - RTC_N_PREDIV_S)) - 1)
#define INPUT_SLEEVE_Pin GPIO_PIN_15
#define INPUT_SLEEVE_GPIO_Port GPIOB
#define LED_R_Pin GPIO_PIN_3
#define LED_R_GPIO_Port GPIOB
#define BATTERY_DIVIDER_ON_Pin GPIO_PIN_4
#define BATTERY_DIVIDER_ON_GPIO_Port GPIOB
#define INPUT_TIP_Pin GPIO_PIN_7
#define INPUT_TIP_GPIO_Port GPIOB
#define OUTPUT_SLEEVE_Pin GPIO_PIN_14
#define OUTPUT_SLEEVE_GPIO_Port GPIOB
#define OUTPUT_TIP_Pin GPIO_PIN_10
#define OUTPUT_TIP_GPIO_Port GPIOA
#define LED_B_Pin GPIO_PIN_0
#define LED_B_GPIO_Port GPIOA
#define LED_G_Pin GPIO_PIN_10
#define LED_G_GPIO_Port GPIOB

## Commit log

2023-02-02 Fix ERC warnings
    [power.kicad_sch, ultramote.kicad_sch, usb.kicad_sch]
2023-02-02 Fix DRC warnings
    [ultramote.kicad_pcb]
2023-02-11 Fix Debug connector registration hole diameter
    - closes #1
    [ultramote.kicad_pcb]
2023-02-11 Add datasheet links
    [gpio.kicad_sch, power.kicad_sch, ultramote.kicad_sch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]
2023-02-11 Add Mounting Holes as schematic symbol
    [ultramote.kicad_pcb]
2023-02-11 Update footprint library paths
2023-02-11 Remove battery footprint from PCB export
    [ultramote.kicad_pcb]
2023-02-11 CI: Update documentation
    [bom_ultramote.csv]
2023-02-12 Add logo to PCB backside
    - closes #3
    [ultramote.kicad_pcb]
2023-05-21 Migrate project to KiCad v7
    [SMA_female_edge_6.5x6.5.step, gpio.kicad_sch, power.kicad_sch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]
2023-05-21 Fix USB-C 3D model paths
    [ultramote.kicad_pcb]
2023-05-21 Fix various 3D models
    [ultramote.kicad_pcb]
2023-06-19 Route Output jack through separate ground
    [gpio.kicad_sch, ultramote.kicad_pcb]
2023-07-01 Add option to manually trigger KiCAD CI run
2023-07-01 Improve LED controller comments
2023-07-02 Fix bug in trigger integrator
    [trigger.c]
2023-07-04 Add fast blink pattern to LED controller
2023-07-04 Increase LoRa frequency, ouput power and spreading factor
2023-07-07 Make battery monitor state machine more consistent
2023-07-07 Fix inverted channels in trigger
    [trigger.c]
2023-07-07 Minor refactor in LED controller
2023-07-16 Fix Pin Assignment for Output jack
    closes #4
    [SMA ANGLED.STEP, ultramote.kicad_pcb, ultramote.kicad_sch]
2023-07-16 Add QWIIC connector
    closes #5
    [ultramote.kicad_pcb, ultramote.kicad_sch]
2025-09-28 Update to KiCAD v8
    [gpio.kicad_sch, power.kicad_sch, ultramote.kicad_pcb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]
2025-12-20 Add battery percentage gauge
2025-12-20 Save PCB with latest KiCAD
    [gpio.kicad_sch, power.kicad_sch, ultramote.kicad_pcb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]
2026-09-16 pcb: Replace KiBot with a kicad-cli Makefile
    kicad-cli covers the schematic and PCB PDFs, the renderings, the gerbers, the CPL and fab zip, the STEP export and the BoM, so the KiBot configuration is gone. The interactive BoM still comes from the standalone InteractiveHtmlBom CLI, which has no kicad-cli equivalent, and datasheets are dropped entirely as there is no replacement for them.
    The JLCPCB outputs are raw kicad-cli output: the CPL keeps KiCad's column names and rotations and the BoM is not filtered or rotated for JLC.
2026-09-16 pcb: Update 3D model paths for KiCad 10
    KiCad 10 only ships .step models and its libraries no longer resolve ${KICAD6_3DMODEL_DIR}, which left every model reference unresolved. The variable will need the same rename with the next major KiCad.
    The board no longer carries the stale title block date/version properties.
    [ultramote.kicad_pcb]
2026-09-16 Stop committing generated assets
    The documentation assets are build output: CI hands them to the website job as an artifact instead. pcb/generated and the published copies under website/static are removed from the index only - the f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
    [bom_ultramote.csv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]
2026-09-16 website: Publish assets under pcb_assets
    Renames the published directory from kibot_generated to pcb_assets, points the documentation links at it, drops the KiBot mention in favour of the Makefile and fixes the "Board Layot" typo. Published URLs change.
2026-09-16 CI: Build and publish the website with GitHub Pages
    Replaces the workflow_run chain - whose documentation commit was pushed with GITHUB_TOKEN and therefore never triggered the next workflow - with a single workflow: the KiCad image builds the assets, the artifact is handed to a publish job and the site is deployed through the official Pages actions. The repository's Pages source has to be set to "GitHub Actions".
    Zola is pinned at 0.22.1 with a verified checksum because 0.23 moved to Tera v2, which dropped the macro/import tags used by the site templates and the juice theme.
2026-09-16 README: Document the kicad-cli asset build
    Describes make and make OUT usage, the KiCad 10 and bsdtar requirements, the InteractiveHtmlBom venv and the Zola 0.22 requirement for the website.
2026-09-16 pcb: Find the InteractiveHtmlBom CLI in the KiCad plugin install
    The plugin installed through KiCad's Plugin and Content Manager bundles the same CLI as the PyPI package, so it can be used directly: prefer a CLI on PATH, otherwise the plugin copy of the newest KiC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

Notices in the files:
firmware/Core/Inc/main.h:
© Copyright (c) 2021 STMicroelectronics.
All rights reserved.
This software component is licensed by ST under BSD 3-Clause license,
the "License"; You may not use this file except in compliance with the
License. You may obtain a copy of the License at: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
